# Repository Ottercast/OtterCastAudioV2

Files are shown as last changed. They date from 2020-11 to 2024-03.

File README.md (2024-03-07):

# OtterCastAudioV2

OtterCast is an open-source audio streaming device running Linux.
Based on a Sochip S3 SoC, featuring a Webinterface, shairport-sync, snapcast, Spotify Connect and pulseaudio sink/source.

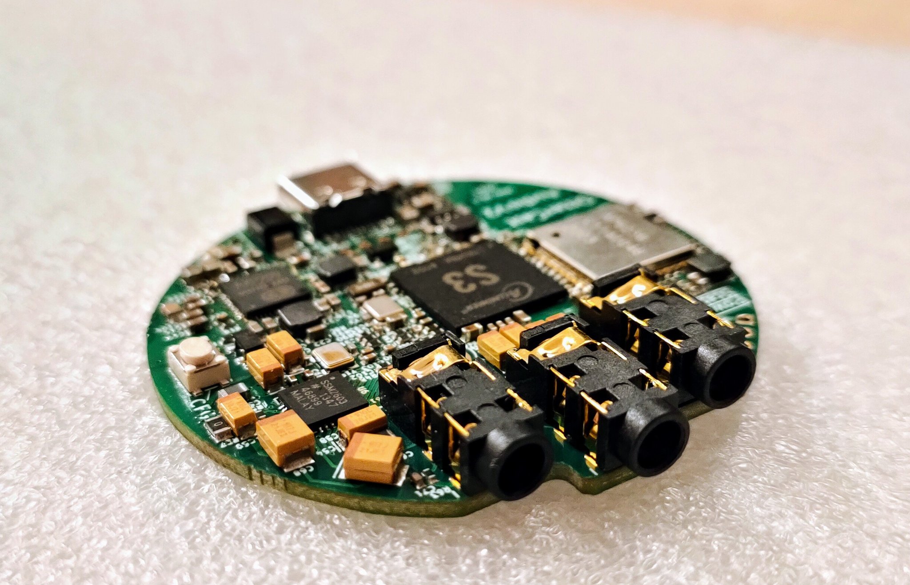
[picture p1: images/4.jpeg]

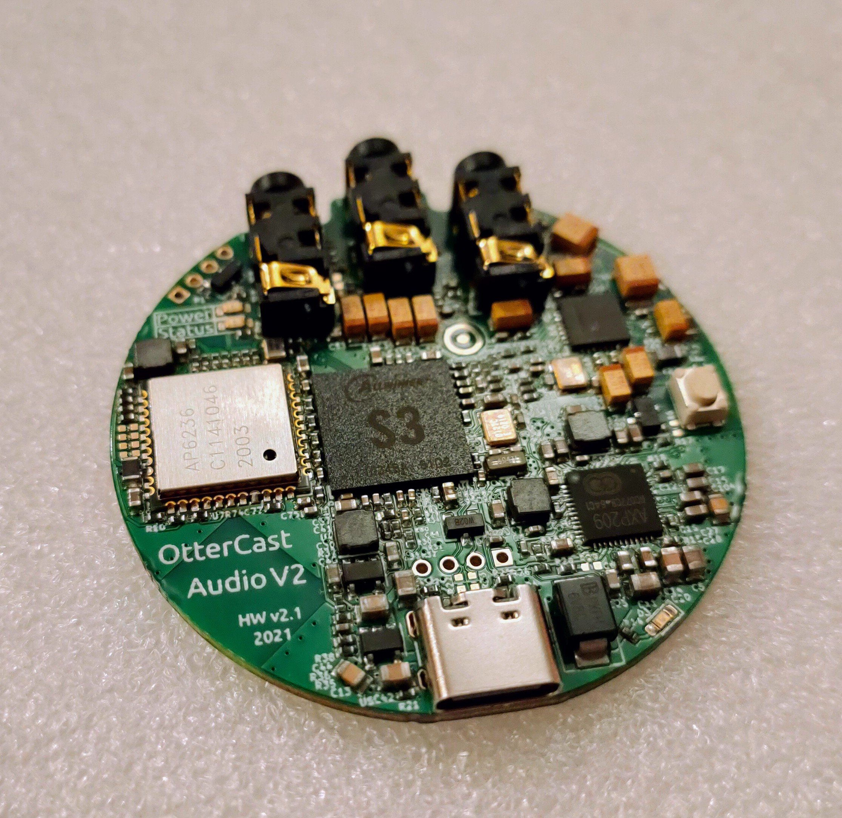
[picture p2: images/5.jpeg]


[Demo Video](https://twitter.com/_Jana_Marie/status/1374088494985969667)

## How do I get one?

~~We are currently planning a small batch production run, stay tuned.~~ Sorry, we don't 🙈

You don't want to wait? You can of course run a small batch on your own! Please have a look into the [production folder](/production_v2.1), a batch size of just 5 (and up to 30) boards is supported by JLC.

## Installation & Configuration

After [downloading and flashing](https://cast.otter.jetzt/docs/firmware/#download-ready-made-images) the image, OtterCastAMP can either be configured via the `config.ini` file or via the web-interface.

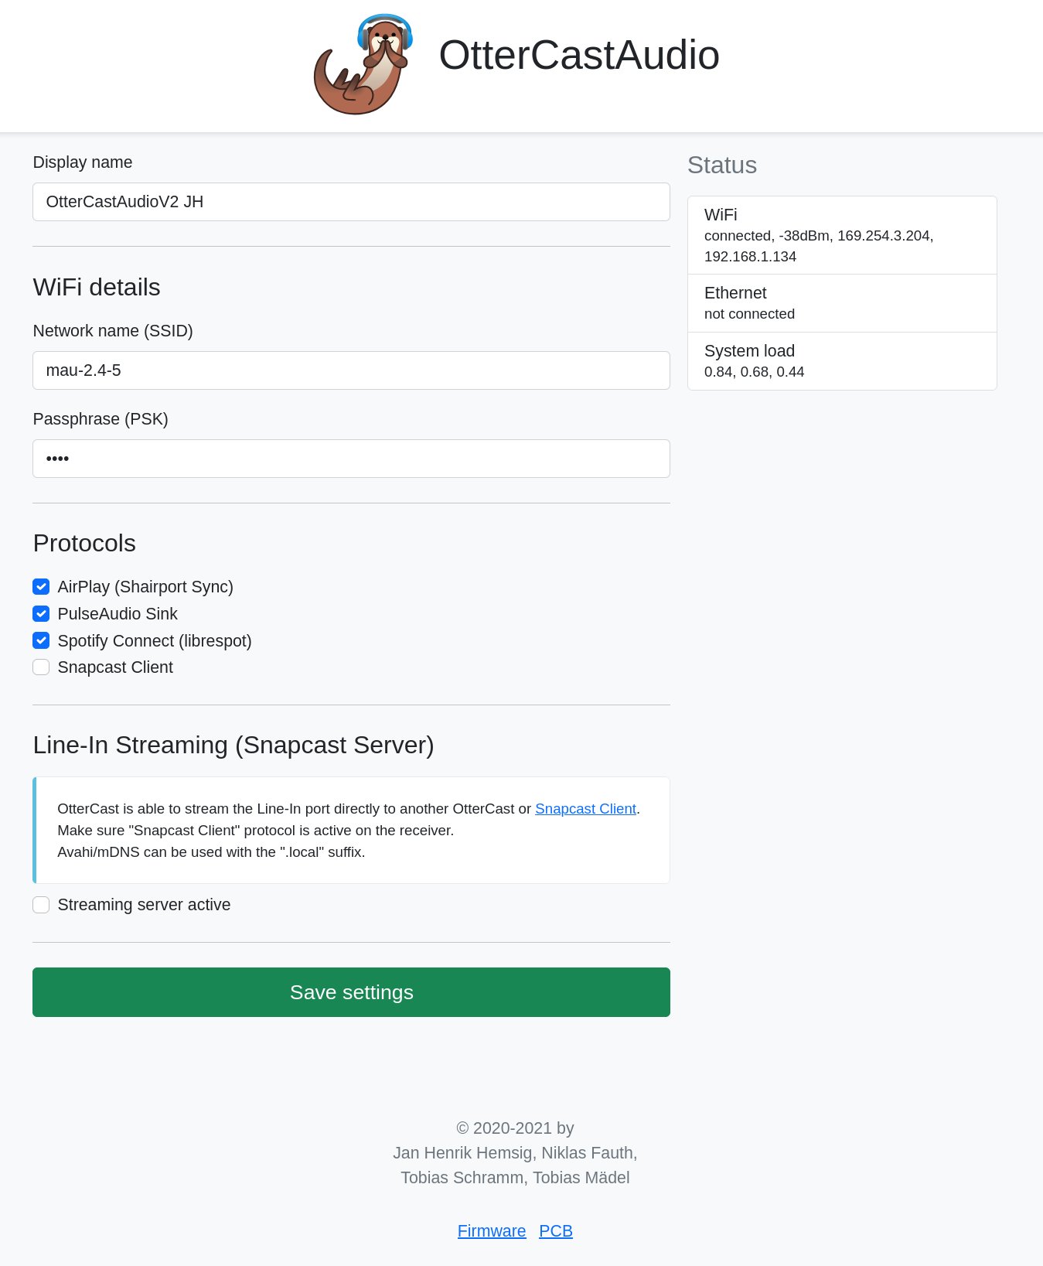
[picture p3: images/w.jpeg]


Check out our [Documentation](https://cast.otter.jetzt/docs/) for more information!

## Schematics?

[Schematics!](/OtterCastAudioV2.pdf)

## Team

 - [@lucysrausch](https://twitter.com/lucysrausch) Hardware - OtterCastAmp
 - [@_Jana_Marie](https://twitter.com/_Jana_Marie) Hardware - OtterCastAudio
 - [@Toble_Miner](https://twitter.com/Toble_Miner) Software - Embedded Linux
 - [@Manawyrm](https://twitter.com/Manawyrm) Software - Frontend & OTA

## What happened to OtterCastAudioV1?

Nobody shall ever know

## Status

HW v2.1 is tested and works!

 - [x] Audio Line Out
 - [x] Audio Headphone Out
 - [x] Audio In
 - [x] WiFi
 - [x] Ethernet
 - [x] USB Sound card mode

 - [x] Webinterface (config)
 - [x] Shairport-sync
 - [x] Pulseaudio sink/source
 - [x] snapcast server/client
 - [x] Spotify Connect (librespot)

## License

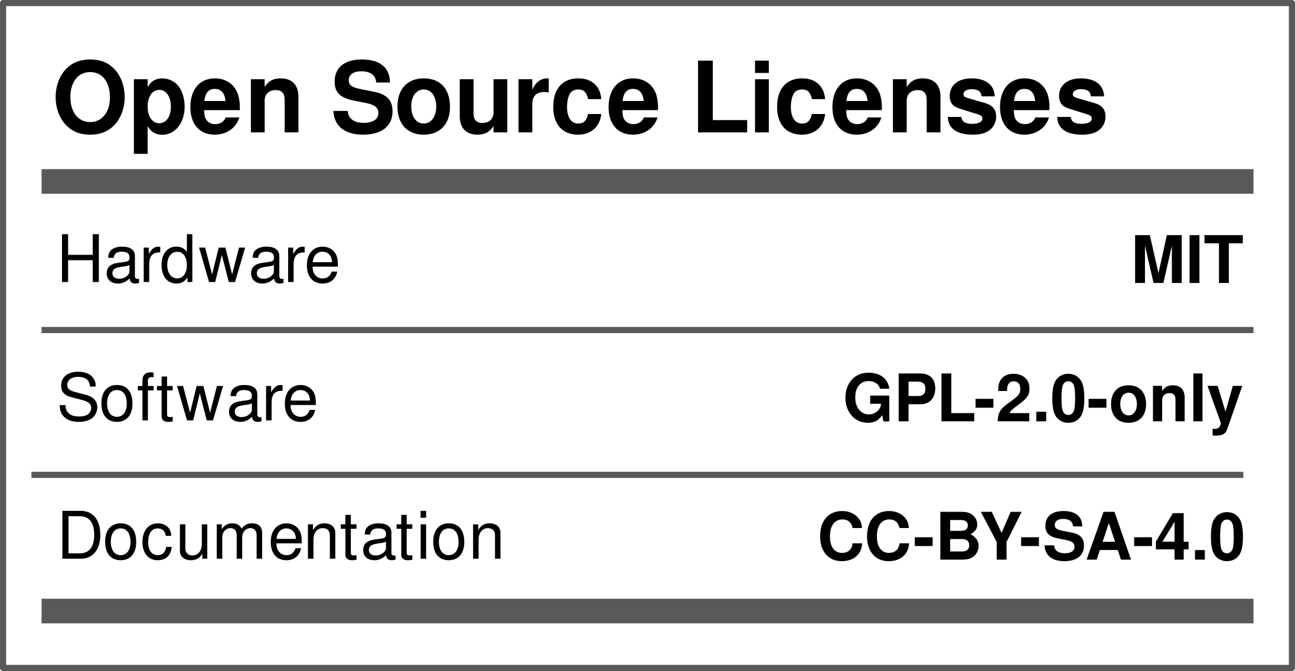
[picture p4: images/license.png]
License Banner (https://certification.oshwa.org/de000109.html)


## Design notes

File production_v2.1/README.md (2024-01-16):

# Notes

All production files are optimized for [JLCPCBs SMT service](https://cart.jlcpcb.com/quote?orderType=1). The gerbers are located in `OtterCast_combined-v2.1.zip` and as for the BOM and position file please refer to `BOM_v2.1.csv` and `POS_v2.1.csv`.

Please choose `1.6mm`, `impedance control`, `ENIG`, `Specify order number location`, `SMT Top side assembly` and `tooling holes added by customer` as board options. 

The `BOM_v2.1.csv` does not contain all parts, since JLC does not sell all parts. Please refer to the following list for the manual assembly parts.

Or [jump to the Images section](https://github.com/Ottercast/OtterCastAudioV2/blob/main/production_v2.1/README.md#jlc-images) of this README to see how to order the boards.

| Designator | Part | Layer | LCSC  | Other |
| --- |:---:|:---:|:-----:|:-----:|
| U1 | Sochip s3 | Top | - | [aliexpress](https://aliexpress.com/item/4000208092272.html) |
| U7 | AP6236 | Top | [C2908817](https://www.lcsc.com/product-detail/WiFi-Modules_AMPAK-Tech-AP6236_C2908817.html) | |
| X1 | 26Mhz TCXO | Top | [C669081](https://lcsc.com/product-detail/SMD-Oscillators-XO_Yangxing-Tech-OT201626MJBA4SL_C669081.html) | |
| U6 | SSM2603 | Top | [C691080](https://lcsc.com/product-detail/Pre-ordered-Products_Analog-Devices_SSM2603CPZ-REEL_Analog-Devices-ADI-LINEAR-SSM2603CPZ-REEL_C691080.html) | [aliexpress](https://www.aliexpress.com/item/33014054478.html) |
| U3 | AXP209 | Top | [C80525](https://lcsc.com/product-detail/PMIC-Battery-Management_X-Powers-Tech-AXP209_C80525.html) | |
| J5,J6,J7 | PJ-3270 | Top | [C381134](https://lcsc.com/product-detail/Audio-Video-Connectors_XKB-Connectivity-PJ-3270_C381134.html) | |
| J2 | DM3D-SF | Bot | [C719027](https://lcsc.com/product-detail/Card-Sockets-Connectors_HRS-Hirose-DM3D-SF_C719027.html) | |
| AE1 | KH-5220-A56 | Bot | [C504003](https://lcsc.com/product-detail/Antennas_Shenzhen-Kinghelm-Elec-KH-5220-A56_C504003.html) | |
| AE1 | 0R 0402 | Bot | [C242160](https://lcsc.com/product-detail/Chip-Resistor-Surface-Mount_PANASONIC-ERJ2GE0R00X_C242160.html) | |

## JLC Images

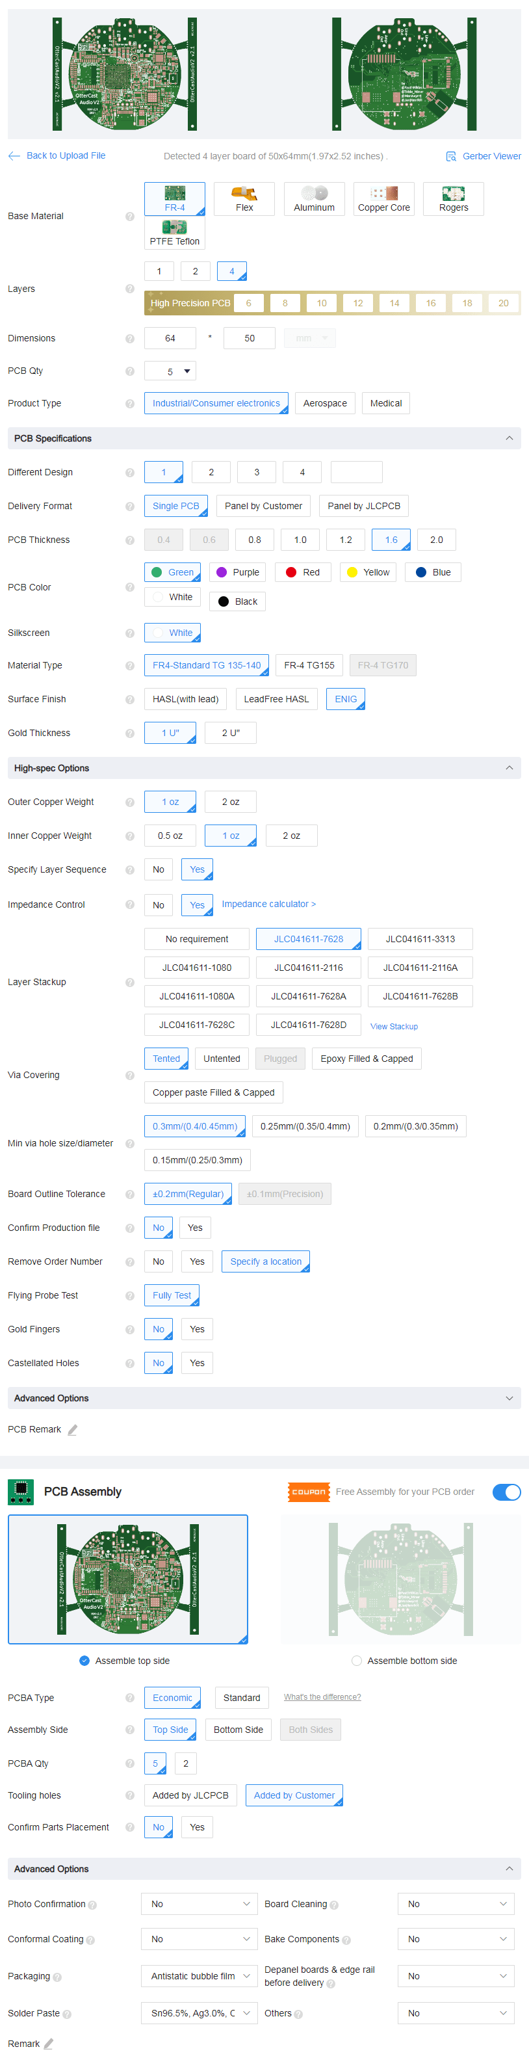
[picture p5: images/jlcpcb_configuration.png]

If you can't select the layer sequence, try changing the *Layers* to 6, then back to 4. For some reason, it sometimes doesn't load correctly on JLCPCB's website.
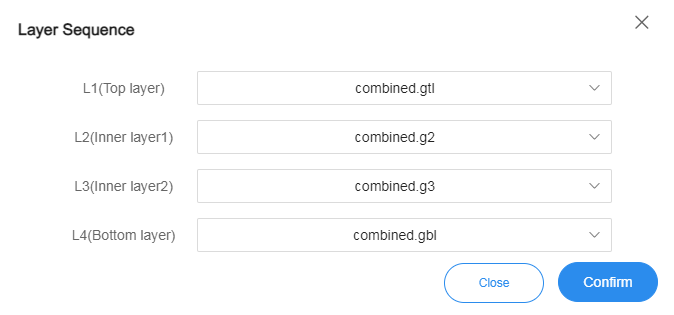
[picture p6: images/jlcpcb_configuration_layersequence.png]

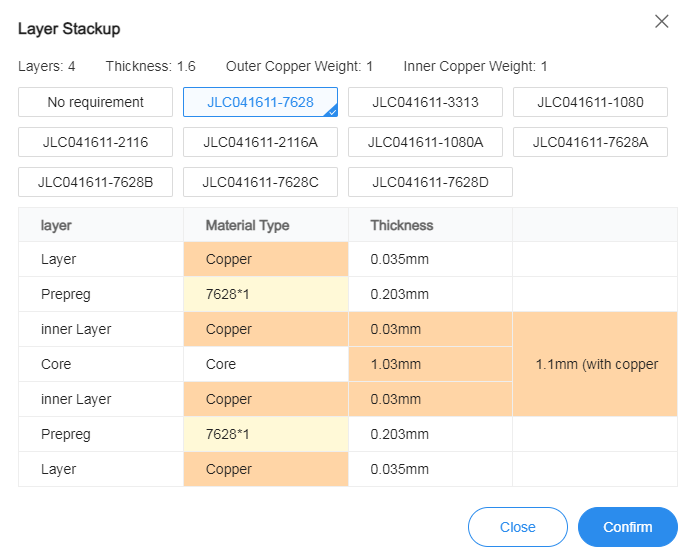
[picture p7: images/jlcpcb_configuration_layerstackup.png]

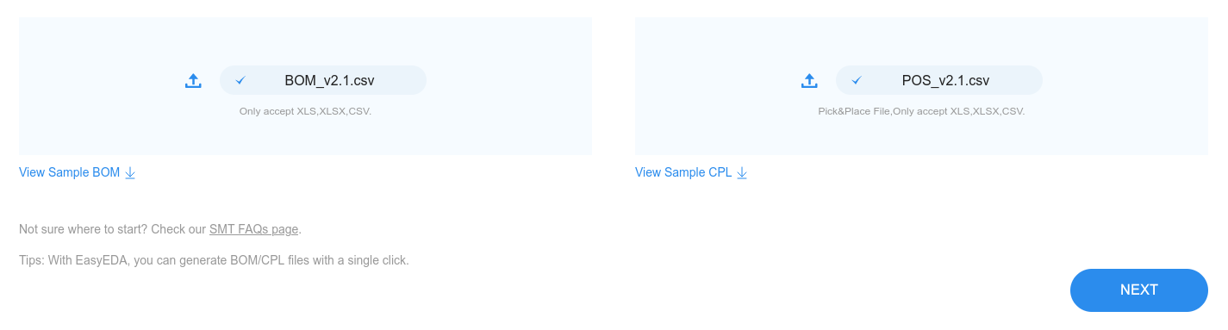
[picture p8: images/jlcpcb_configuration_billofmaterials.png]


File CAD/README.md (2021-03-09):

# OtterCastAudioV2-CAD

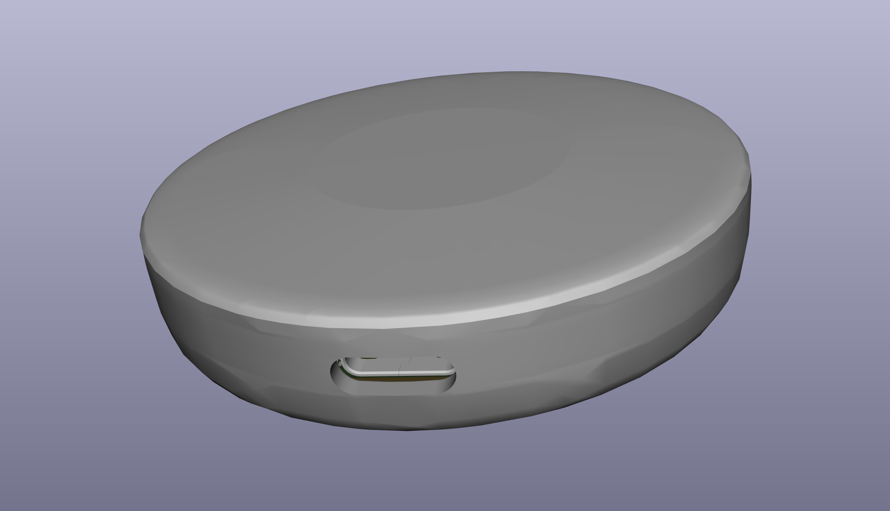
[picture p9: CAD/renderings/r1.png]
Rendering 1 USB

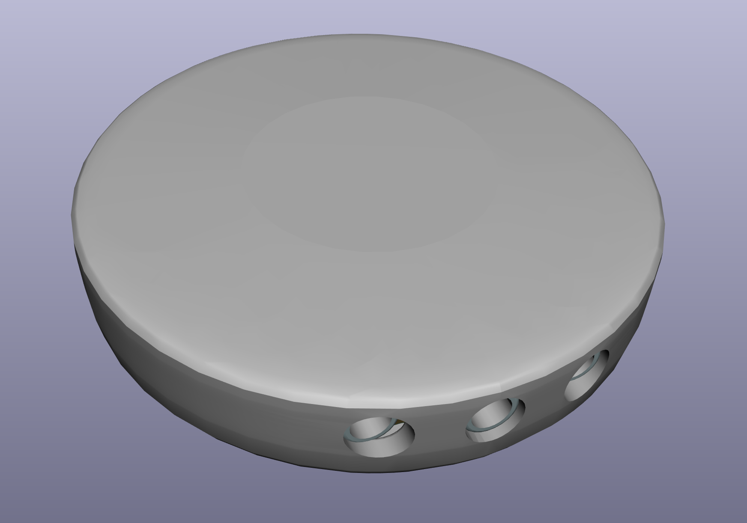
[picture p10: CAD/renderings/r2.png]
Rendering 2 Audio


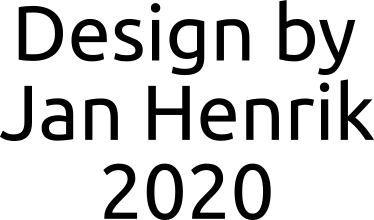
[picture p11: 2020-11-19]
graphics/OtterCastAudioV2_DesignBy.png

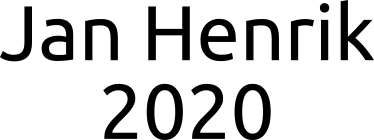
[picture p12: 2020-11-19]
graphics/OtterCastAudioV2_JH_2020.png

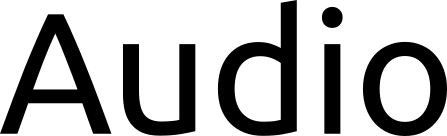
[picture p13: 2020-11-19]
graphics/OtterCastAudioV2_2.png

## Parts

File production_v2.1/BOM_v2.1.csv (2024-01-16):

Comment | Designator | Footprint | LCSC
KH-5220-A56_U.FL | AE1 | otter:KH-5220-A56 | C504003
47u | C11,C10,C5,C42,C43,C45 | otter:C_0805 | C45783
1n | C12,C47 | otter:C_0402 | C1523
1n | C13,C104 | otter:C_0805 | C46653
470n | C2 | otter:C_0402 | C47339
100n | C37,C38,C35,C36,C33,C34,C32,C44,C7,C8,C15,C21,C18,C58,C59,C66,C65,C61,C76,C73,C89,C99,C98,C102,C103,C88,C82,C85,C101,C100,C83,C3 | otter:C_0402 | C1525
10u | C4,C1,C17,C16,C22,C23,C20,C19,C24,C25,C26,C27,C28,C29,C14,C6,C39,C41,C30,C31,C74,C72,C48,C92,C95,C90,C79 | otter:C_0603 | C19702
DNP | C49 | otter:C_0402 | dnp
18p | C52,C51,C93,C94,C96,C97 | otter:C_0402 | C1549
10u | C54,C55,C62,C60,C63,C64,C57,C56,C69 | otter:CP_EIA-3216-10 | C7171
100u | C67,C68 | otter:CP_EIA-3528-12 | C16133
220p | C70,C71,C50,C53,C46 | otter:C_0402 | C1530
1p | C77,C75 | otter:C_0402 | C1550
10p | C78 | otter:C_0402 | C32949
2.2u | C9 | otter:C_0603 | C23630
LED | D1,D2 | otter:LED_0603_1608Metric | C72038
LED | D3 | LED_SMD:LED_0603_1608Metric_Castellated | C72043
P6SMB6.8CA | D4 | Diode_SMD:D_SMB | C78395
ESD5302F | D5,D6 | Package_TO_SOT_SMD:SOT-23 | C239643
FERRET | FB1,FB2,FB3 | otter:R_0805 | C1017
UART | J1 | otter:PinHeader_1x04_P2.00mm_Vertical_nosilk_center | dnp
SD | J2 | Connector_Card:microSD_HC_Hirose_DM3D-SF | C719027
USB | J3 | otter:USB-C 16Pin | C165948
OTG | J4 | otter:PinHeader_1x04_P2.00mm_Vertical_nosilk_center | dnp
PJ-3270 | J7,J6,J5 | otter:PJ-3270 | C381134
49F-1201GYD2NL | J8 | otter:49F-1201GYDXNL | dnp
2.2uH | L2,L1,L3,L4 | Inductor_SMD:L_Taiyo-Yuden_MD-3030 | C167747
2.2uH | L5 | otter:L_0402 | C84472
Mic | MK1 | otter:B4013AM422-42 | dnp
DTA114YKA | Q1 | Package_TO_SOT_SMD:SOT-23 | C111713
100 | R1,R33,R32,R61,R62 | otter:R_0402 | C25076
200k | R16,R21,R40,R78 | otter:R_0402 | C25764
22 | R2,R34,R15,R54,R77,R76,R81 | otter:R_0402 | C25092
0R | R27 | otter:R_0805 | C17477
2k2 | R28,R37,R17,R50,R51,R49,R48,R41,R87,R88,R79,R80 | otter:R_0402 | C25879
DNP | R29,R22,R23,R6,R47,R52,R69,R68,R67,R66 | otter:R_0402 | dnp
5k1 | R3,R4,R30,R35,R36,R39,R24,R25,R14,R86 | otter:R_0402 | C25905
3k3 | R31 | otter:R_0402 | C25890
3k9 | R38 | otter:R_0402 | C51721
680 | R43 | otter:R_0402 | C25130
0 | R44,R45,R46 | otter:R_0402 | C17168
47k | R7,R8,R9,R10,R11,R12,R13,R26,R18,R58,R60,R59,R63,R42,R73,R72,R71,R70,R65,R64,R75,R74 | otter:R_0402 | C25792
240 | R82,R83 | otter:R_0402 | C25094
10M | R84 | otter:R_0402 | C26082
6k04 | R89 | otter:R_0402 | C25913
51 | R91,R90,R93,R92 | otter:R_0402 | C25125
RST | SW3 | otter:SW_SPST_PTS810 | C92589
AllWinner-S3(FBGA-234) | U1 | otter:FBGA-234(Pitch-0.65mm_Pad-0.3mm_11x11x1.08mm) | C2886811
AXP209(QFN-48) | U3 | otter:QFN-48-1EP_6x6mm_P0.4mm_EP4.05x4.05mm | C2997895
SY8089AAAC | U4 | Package_TO_SOT_SMD:SOT-23-5 | C78988
SY6280AAC | U5 | Package_TO_SOT_SMD:SOT-23-5 | C55136
SSM2603 | U6 | otter:LFCSP-28-5x5mm-0.5mm-EP3.14x3.14mm | C691080
AP6236 | U7 | otter:LGA_44_12x12mm_0.9mm | C2908817
26Mhz TCXO | X1 | otter:2016_SMD_CRYSTAL | C132147
12.288Mhz | Y1 | otter:Oscillator_3225 | C70567
32.768kHz | Y2 | otter:Crystal_SMD_3215-2Pin_3.2x1.5mm | C32346
24MHz | Y3 | otter:Oscillator_3225 | C89577

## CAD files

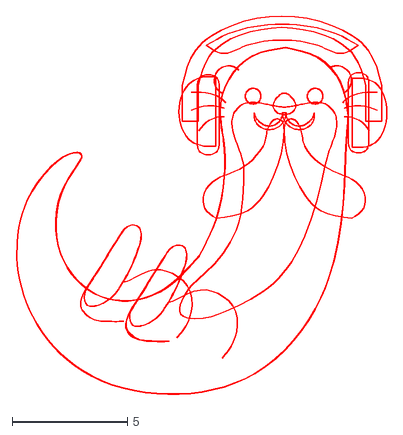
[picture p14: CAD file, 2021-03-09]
CAD/OtterCastLogo.dxf
16.1 x 16.5

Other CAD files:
CAD/case_bot.ipt
CAD/case_top.ipt

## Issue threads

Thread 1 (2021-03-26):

JLC reported issue with trace near PCB edge

Manawyrm, 2021-03-26:
Kenny Stier reported:
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

This'll probably be fixed by resubmitting (maybe without impedance control), but updated gerbers (if possible) would be ideal.

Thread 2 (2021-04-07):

Does it support the Chromecast API?

FutureSharks, 2021-04-07:
Like can I just "cast" from all apps on my android phone?

Jan--Henrik, 2021-04-07:
Sadly the "cast" protocol used by google is not open source nor is there any compatible open source software. It is not supported, so no.

FutureSharks, 2021-04-07:
That's a shame but there is some other reverse engineered examples I think?

https://github.com/ajhsu/chromecast-device-emulator
https://github.com/vbaicu/mMusicCast

Gartral, 2021-04-07:
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

I'm just doing my toes into the otter cast project, so this is a high level skim of the above projects. At first glance it appears that mMusicCast is closer to what you're looking for, but I have serious missgivings about trying to shoehorn a full electron app into 128mb of RAM.

I'll profile MMC later today and update from there. If it fits, this might be as simple as bake it in and turn it on.

CDE isn't suitable at all from their own admission of having to previously have a cast "sink" and basically doing a replay attack to force an app to talk to the server. Seems like it's more geared for having together your own castable apps rather than using it as a legit sink.

Jan--Henrik, 2021-04-07:
Thanks @Gartral! As a sidenote, MMC does not seem to be a "cast" receiver, it is just a spotify and youtube receiver. We already support spotify, so this does not add alot.

Gartral, 2021-04-07:
Yea, MMC is only a partial implementation of the Cast/mDNS protocol. From what I can tell so far, Google Cast is a "closed ecosystem, with an open door". I popped the $5 to poke around in the google Cast Dev SDK site and I see an option for making a new receiver. Now, if my understanding of mDNS and the Cast Protocol works, we aren't exactly piping audio straight from one device to another, as we are requesting the cast receiver to go find what we asked it to play and just play it, on it's own.

In short, while it DOES look like we can implement Cast Audio on the ottercast, this will incur a running cost as we're going to need a publicly accessible server to "bounce" off of, and is partially reinventing the wheel for the project as Cast appears to be a loose collection of apps that all agree that Cast is an acceptable user agent, more than it is just a direct pipe. It's possible to implement, but the question is; Is it worth it? And worth how much?

Manawyrm, 2021-04-08:
`publicly accessible server`
-- running servers is no issue, we have more than enough infrastructure at hand.

I'd like if that infrastructure could be self-hosted, though, to avoid shutting down people's OtterCast when our servers go down.

I'm personally using no devices capable of sending the Cast protocol, but would still be interested in implementing the feature.
Can you assess whether that server would actually need to transport any media data or just handshaking/API calls?
I'm guessing this would require some serious development time, though :/

Gartral, 2021-04-13:
Sorry! my laptop was down for a few days (keyboard died). As far as I understand it, the Cast protocol doesn't stream the data itself from device to device, but the server is needed as a common reference point to do NAT walking and handshakes. The dev work, after digging into it, doesn't look like it's insurmountable but it WILL require shoehorning a "minified" Google Chrome browser into the OtterCast.

And I know from experience that the google home mini speakers can be used with some specific software on Linux as a target for pulse, but the latency is absolutely atrocious, on the order of seconds. The best I've been able to get is 3-4 seconds behind a youtube video. The average, without mucking around with a lot of networking first, is closer to 10 often north of that. And while I haven't looked directly, I suspect part of that is the handshake, I'll dig more into it.

In short: I don't personally see it as a good alternative to the other capabilities that the Ottercast has built in. It would only really be usable to cast audio from a phone to the OC.

Manawyrm, 2021-04-13:
> require shoehorning a "minified" Google Chrome
Yeah, I don't see this happening at all on the platform.
With 128 MB RAM (half of it is already used) and the rather slow 32bit ARMv7, running any kind of CEF, WebKit, Chromium, etc. is pretty much out of the question.

Gartral, 2021-04-13:
64MB of ram is... doable. It'd be tight as hell, don't get me wrong, but it may well be doable. The original Nest Mini had a Synaptics AS370 with 256MB of ram.

Of course, the latest gen is the Home Mini with a Marvell 88DE3006 and 512MB of RAM. But if we're too clever by half, and disable a bunch of features when we're in "Cast mode" then we might be able too eek out a usable experience. This again wraps back around to my original point of "How badly do we want this?". if we're careful and manage it right, it might be doable.

I'm looking into how much of the Nest/Home's ram is used by the "os" and there isn't a lot of info there. But I suspect the actual usage for Cast/mDNS isn't too far off our target (Keeping in mind that the google devices have so far, to my knowledge, never been hacked and firmware dumped)

blurpy, 2021-06-26:
> How badly do we want this?

I've been looking for an alternative to the Chromecast Audio for years, so I dread the day my old one dies. Google only wants to sell speakers, and the other options are usually quite expensive and big.

I don't know if it will work on the current generation of hardware or not, but making a device that accepts casts from any audio app on Android is really useful. And even better if it supports toslink, for a full Chromecast Audio replacement.

raress96, 2022-06-22:
Just came across this issue while searching for an Open Source Google Cast receiver.
I presume this is not going to be implemented any time soon right?

phaidros7, 2025-04-15:
Actually 2 questions:

1)

Maybe I am on the wrong foot here and even be reanimating a corpse of a feature request .. but for the sake of having a dozen Chromecast Audio Devices in my home and in the desperate search for suitable wifi enabled sink devices (turntable!), I came across Otter :)

All Otter Chromecast Audio compatibility related docs lead to this ticket.

I understand that Chrome on the device is to bloated, but I am using mkchromecast rather successfully from my linux clients and wonder, if that is something the Otter is maybe capable to run:

https://github.com/muammar/mkchromecast

If so, would it be useful to incorporate?

2)

My second question is: was there any approach to Google if they might open up the Cast protocol already? What would be a way to address that with them?

I'd love  to see and support a solution with which the old Chromecast Audio Devices are given a way longer live.

Manawyrm, 2025-04-15:
> I understand that Chrome on the device is to bloated, but I am using mkchromecast rather successfully from my linux clients and wonder, if that is something the Otter is maybe capable to run:

Isn't this the wrong direction? This looks like it's a tool to stream audio _TO_ other Chromecast devices.

phaidros7, 2025-04-15:
> > I understand that Chrome on the device is to bloated, but I am using mkchromecast rather successfully from my linux clients and wonder, if that is something the Otter is maybe capable to run:
>
> Isn't this the wrong direction? This looks like it's a tool to stream audio _TO_ other Chromecast devices.

Nope, it is actually what I am looking for: an open source software/hardware bundle to use as a source for my network audio, and for now the sinks are Chromecast Audio.

I understood otter to be able to get a line signal and distribute it to the other otter devices in the network, is that correct?

Manawyrm, 2025-04-15:
> Nope, it is actually what I am looking for: an open source software/hardware bundle to use as a source for my network audio, and for now the sinks are Chromecast Audio.

Ah! OK -- that's not what most people here are looking for :)
It could probably be implemented, but you're the first person asking for that 😸

I think I'd recommend getting a regular Raspberry Pi with an external sound card and just running mkchromecast on that...

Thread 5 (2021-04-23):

TOSLINK suport

jonfen, 2021-04-23:
Any plans to support TOSLINK like Chromecast Audio did?

https://www.carousell.sg/p/chromecast-audio-3-5mm-mini-toslink-to-toslink-optical-cable-119491765/

Manawyrm, 2021-04-23:
The current hardware connects the I2S audio directly into the DAC / audio-codec, but there's a device in planning, which should be able to do either SPDIF/Toslink. No more detailed infos, yet, sorry!

dearchap, 2022-02-28:
Looks like the BT module is connected to the Allwinner via the I2S pins.

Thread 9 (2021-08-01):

What DAC is onboard?

Jakobovski, 2021-08-01:
Very cool project!

I am wonder what DAC you have chosen for the device?

Manawyrm, 2021-08-01:
Hi!

It‘s an Analog Devices SSM2603!
Technically it‘s a DSD/1-bit DAC.

Jakobovski, 2021-08-01:
Cool!

Closed 2021-08-01.

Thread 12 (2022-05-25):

Integrated circuit shortage or obsolete parts management

Marin-Dodouss, 2022-05-25:
Hello Ottercast hardware and firmware developpers,

I downloaded Ottercast open source project.
First, a huge thanks because it was exactly what I was looking for.
Then, I tried to order the assembled PCB but some components are noted as inventory shortage on JLCPCB. (On octopart too)
Maybe, I can found alternate parts for some, but the AXP209 seems unavailable.

Did you plan to change this component ?

If you need, I think I can made a fork and do components changes using Kicad but I don't know if doing this will broke the software or not.

Do you have any advices ?

Manawyrm, 2022-05-25:
Hi!
IIRC the AXP currently isn't really used in the software, so anything that can supply the required voltages (with the required power sequencing) should do the trick.
There are a lot of similar chips in the AXP line, you might find a compatible one.

Marin-Dodouss, 2022-05-25:
Hi !
Thanks for your quick answer !
I'll try to find an alternate part next week.
If it's okay, I'll put it into the BOM.

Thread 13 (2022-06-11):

AirPlay 2 Compatibility?

ezadoo, 2022-06-11:
As Shairport-Sync seems to be in the final stages of implementing the AirPlay 2 functionalities, it would be very interesting to know if there is
a) a way of installing the beta-version of shairport-sync
and b) how it will perform on OttercastAudioV2, if it is released.

As I currently don’t have an Device myself, as I hoped I would be able to simply buy a completely working OttercastAudio-board.
And if If i do the additional soldering myself, I would like to know, if I could use it later for AirPlay 2 too.

Manawyrm, 2022-06-11:
> AirPlay 2 functionalities
Yeah, AirPlay 2 is much more involved than AirPlay 1, as it needs strict timing accuracy, would normally also require additional hardware features (but I think we can manage without them).

Generally: The firmware for the Ottercast is built via buildroot from this repository:
https://github.com/Ottercast/buildroot-ottercast-audio
We're already using a custom version of shairport-sync with some mods, which is currently hosted on my GitHub account:
https://github.com/Ottercast/buildroot-ottercast-audio/blob/master/buildroot/package/shairport_sync_pulseaudio/shairport_sync_pulseaudio.mk
This would need to be changed to use the development branch (or the new version when it's released).

Getting the dev version / v2 to work with PulseAudio in general might be a bit of a pain. Maybe it's time to evaluate Pipewire first (or to switch to plain ALSA outright)... The OttercastAmp (not the AudioV2) also seems to still be suffering from some timing / clock-distribution problem which would probably need to be addressed before this starts working properly.

Performance-wise: I don't really expect any trouble there.

... to be direct: Each single one of us in the team have started a new full-time role as an engineer at different companies since we started this project, so time is running a bit low. The OttercastAmp is my daily driver amp and it has reached that status of "good enough, plays music, can worry about other things", which is a dangerous place to be in :smile:

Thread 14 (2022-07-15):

NymphCast support

keunes, 2022-07-15:
Hello
I've been watching this space for a while and it's really cool what you folks are making :) I'm currently using Chromecast a lot but interested in replacing it with an open source stack (so I've following #2 also).

Now, I've also seen NymphCast, some kind of an open source Chromecast replacement, which looks cool as well. Not sure if you were aware of it, so I thought I'd share.

https://github.com/MayaPosch/NymphCast

Quite far away still, but the ultimate dream is to stream audio from AntennaPod and Funkwhale, via NymphCast, to OtterCast :)

keunes, 2022-07-15:
Just realised that there's another repo for the software side, which even already has an issue for NymphCast! 💪
https://github.com/Ottercast/buildroot-ottercast-audio/issues/16

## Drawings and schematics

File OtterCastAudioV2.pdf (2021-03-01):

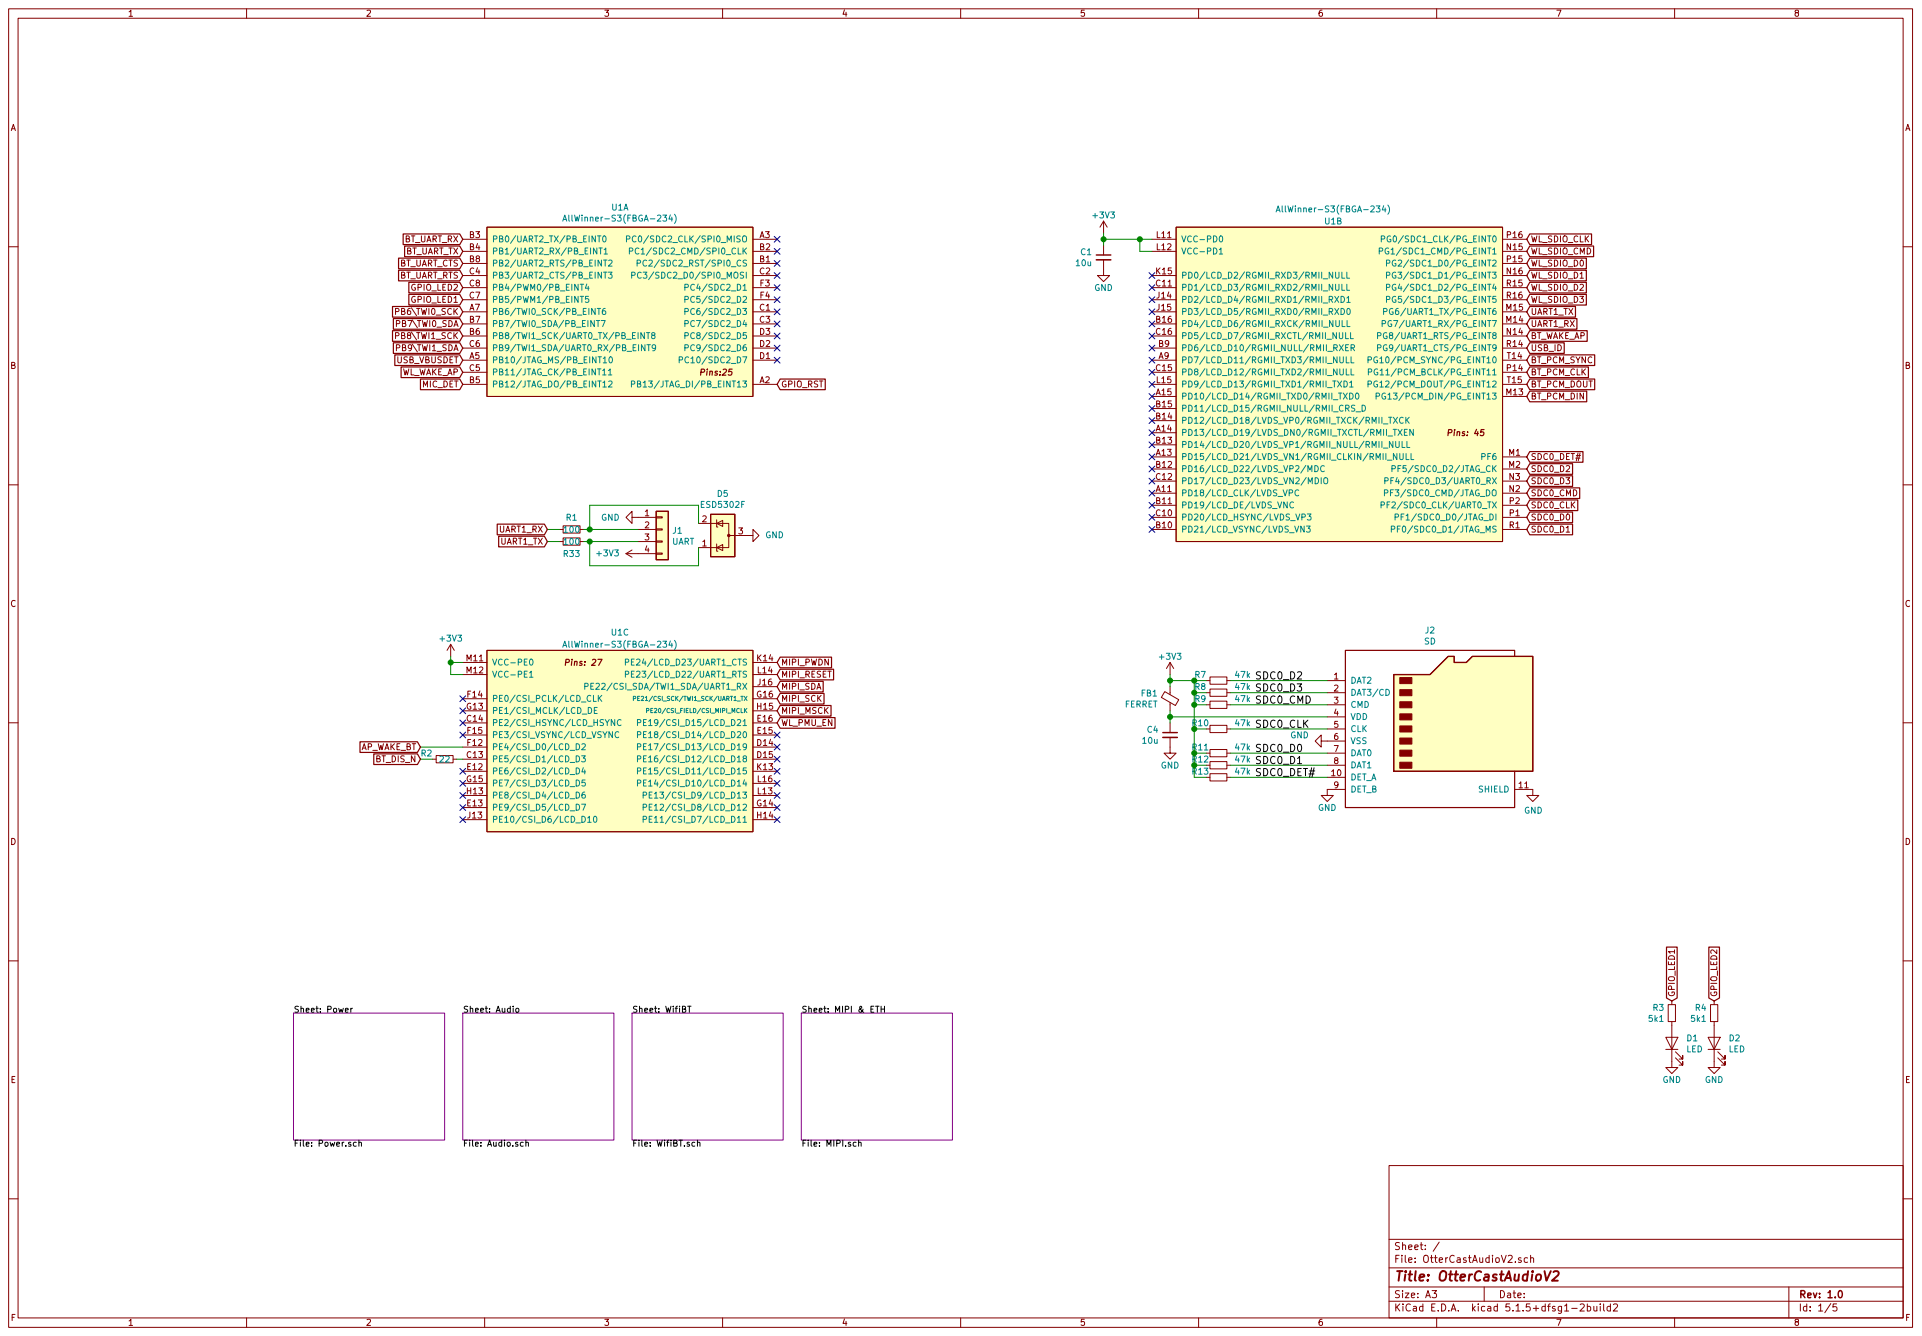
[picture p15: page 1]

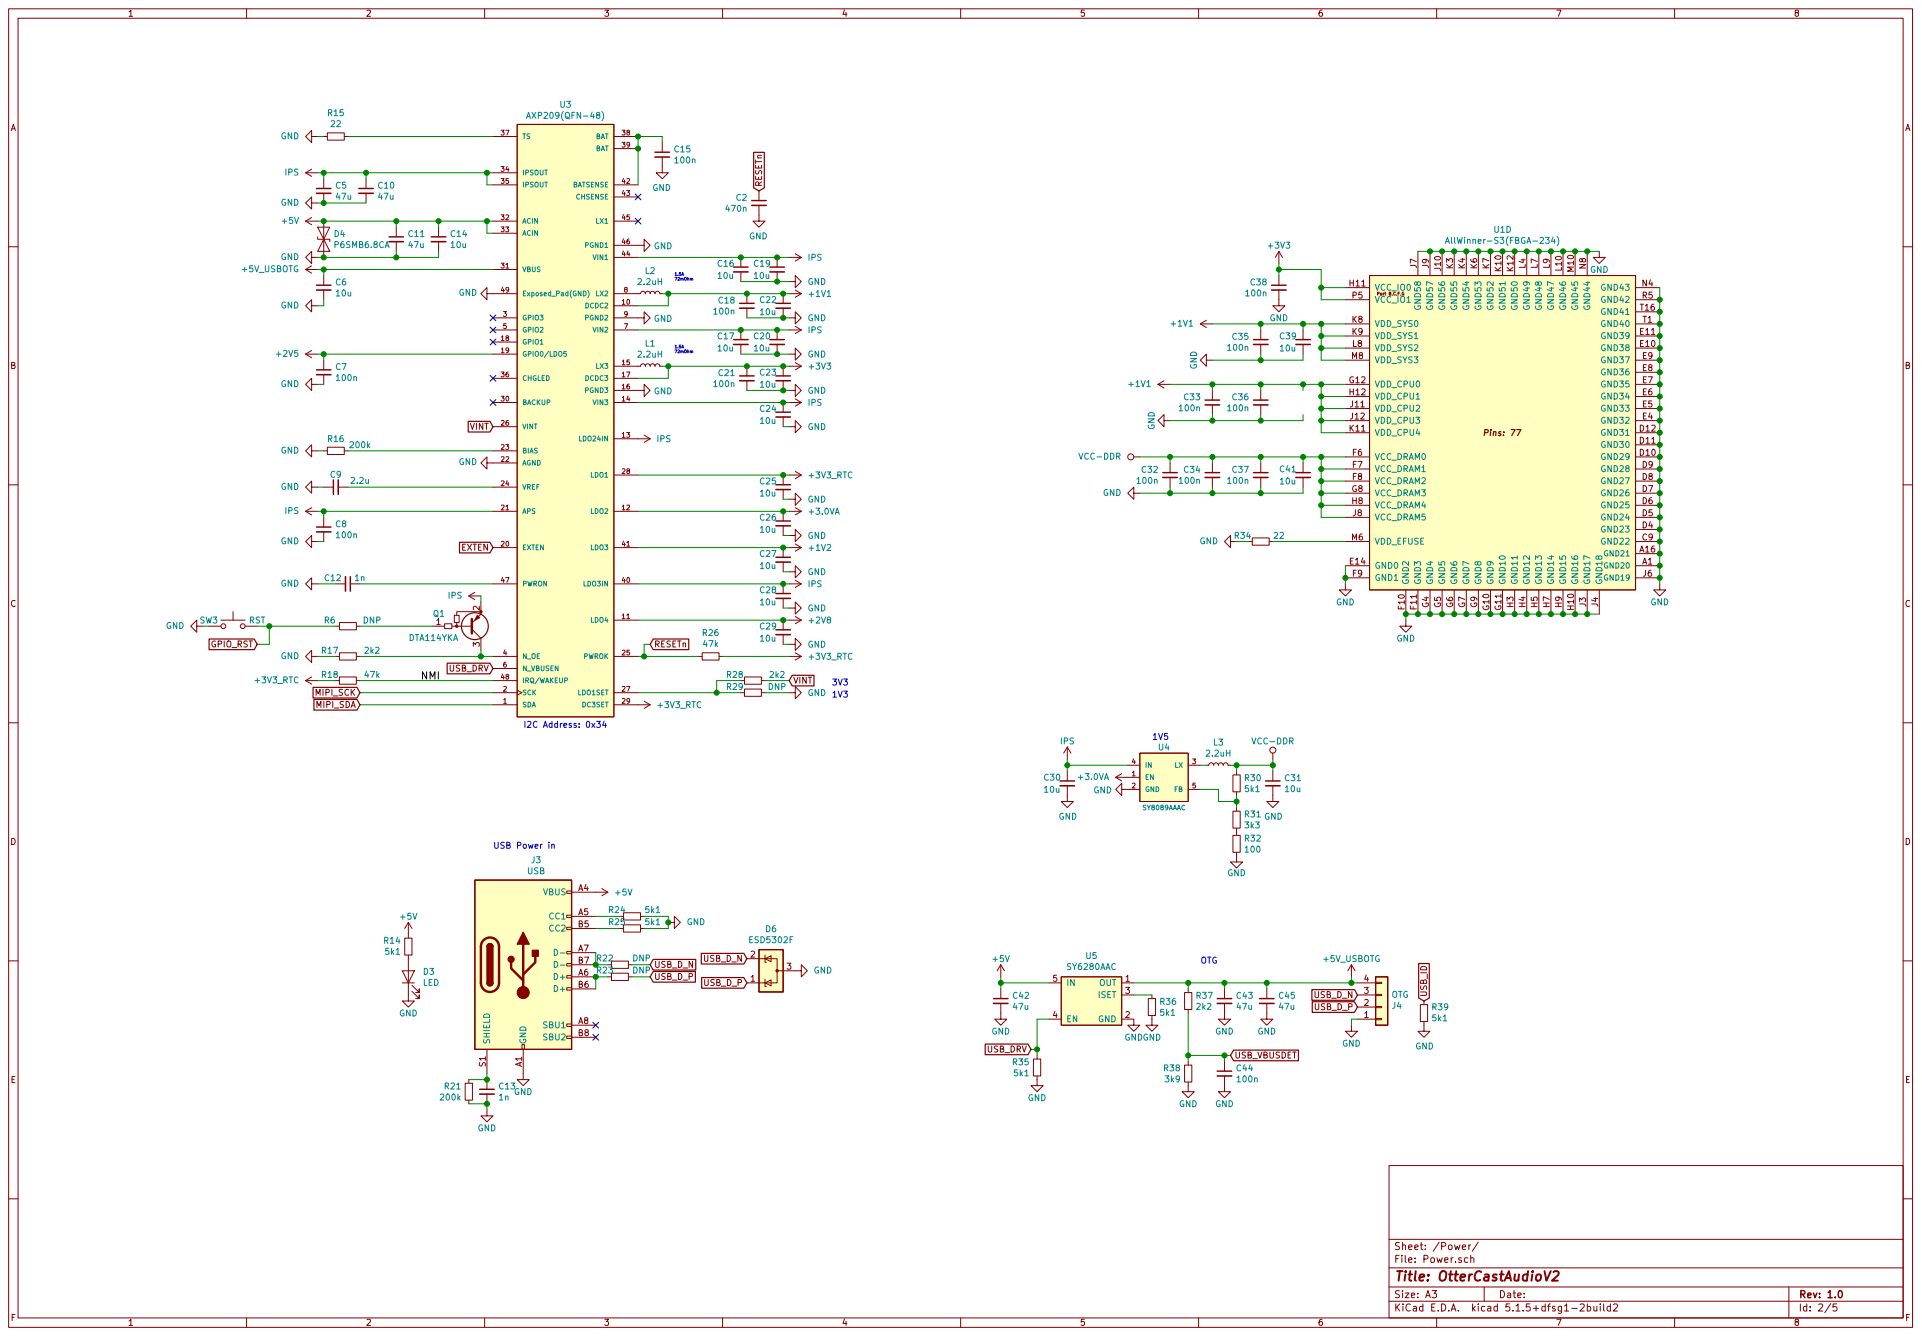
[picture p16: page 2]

File: Power.sch Sheet: /Power/
Id: 2/5 Title: OtterCastAudioV2

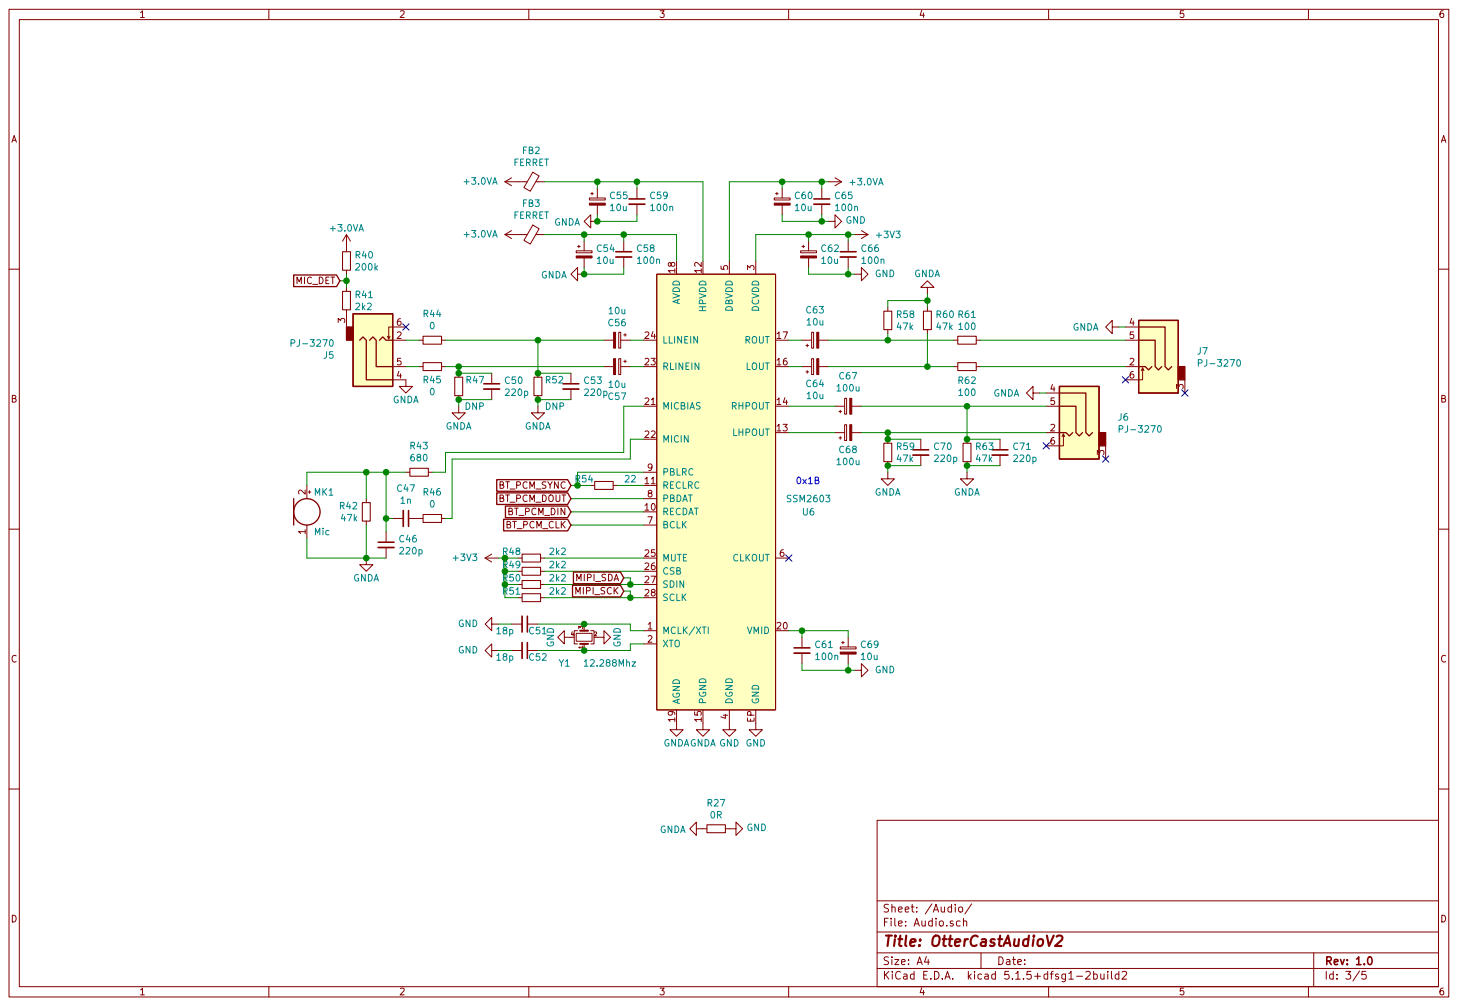
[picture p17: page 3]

5 CLKOUT 6 BCLK 7 PBDAT 8 PBLRC 9 GND EP U6 SSM2603

File: Audio.sch Sheet: /Audio/
Id: 3/5 Title: OtterCastAudioV2

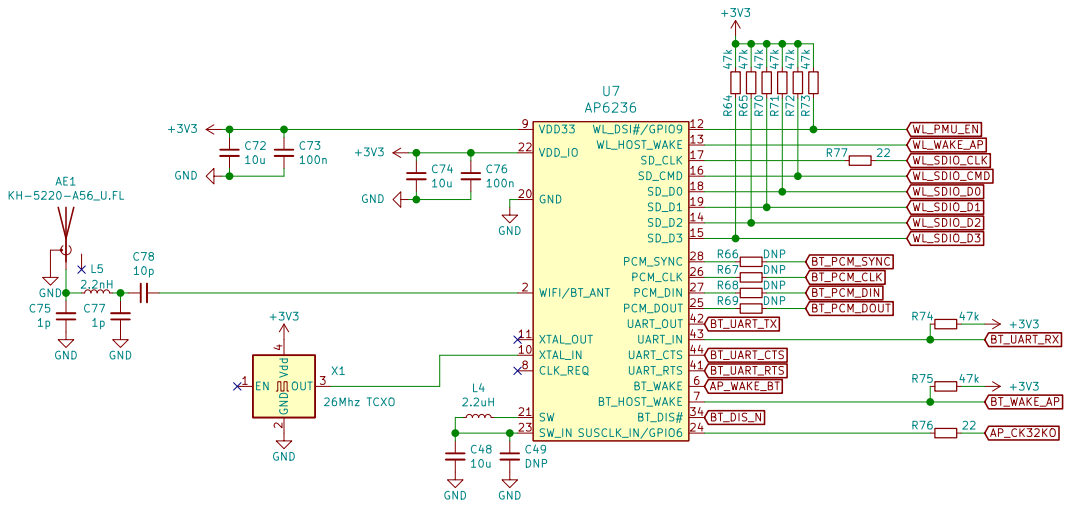
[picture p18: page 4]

File: WifiBT.sch Sheet: /WifiBT/ C75

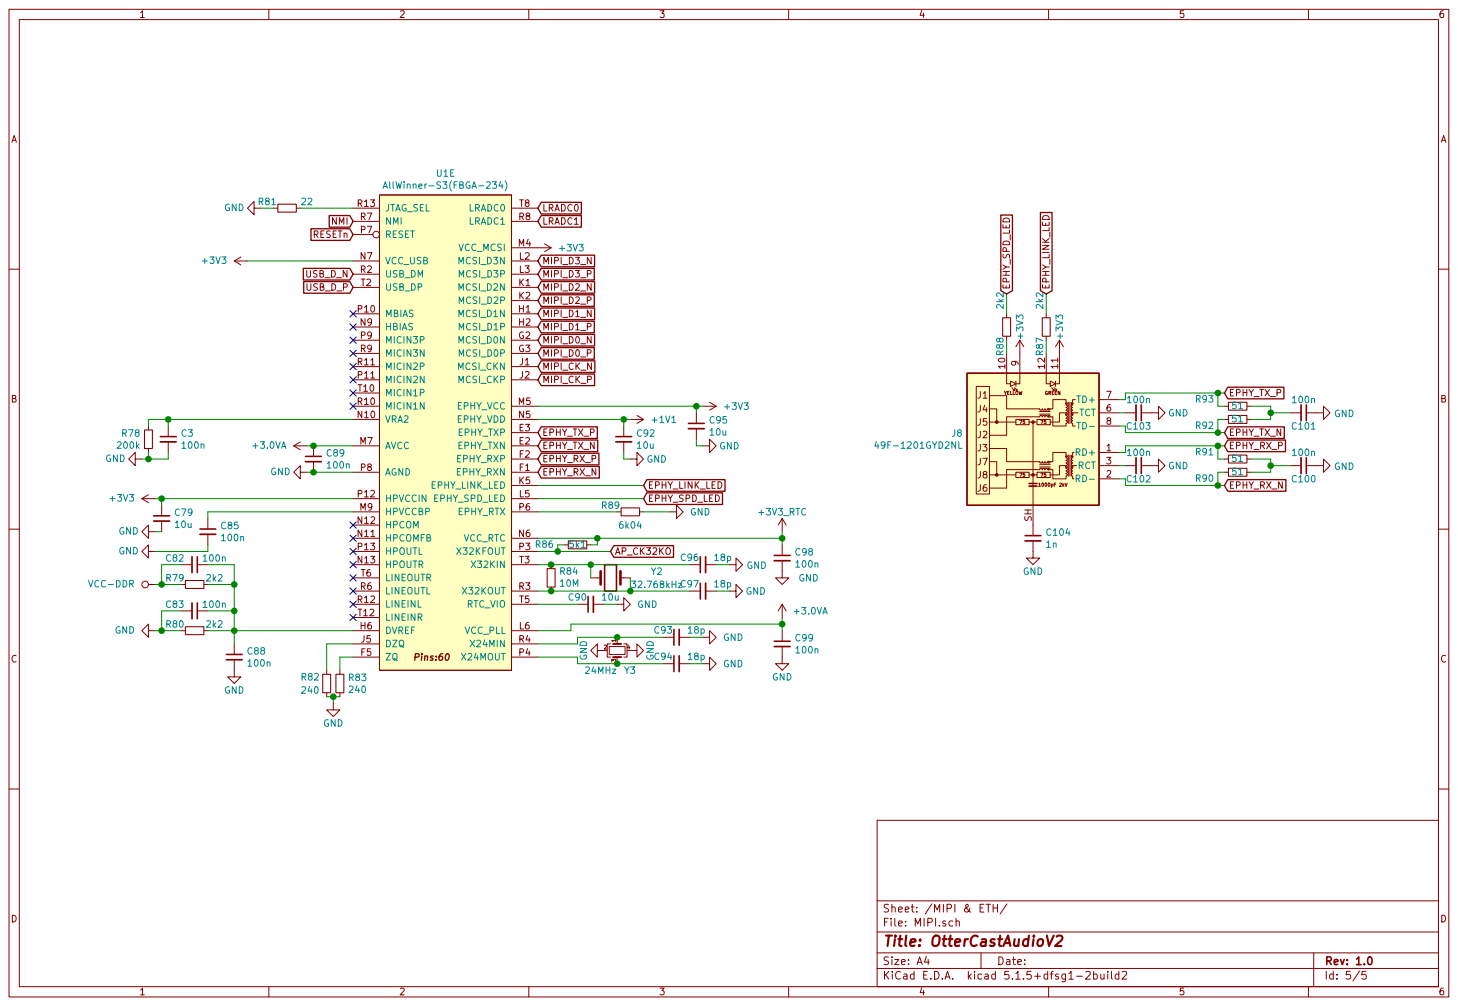
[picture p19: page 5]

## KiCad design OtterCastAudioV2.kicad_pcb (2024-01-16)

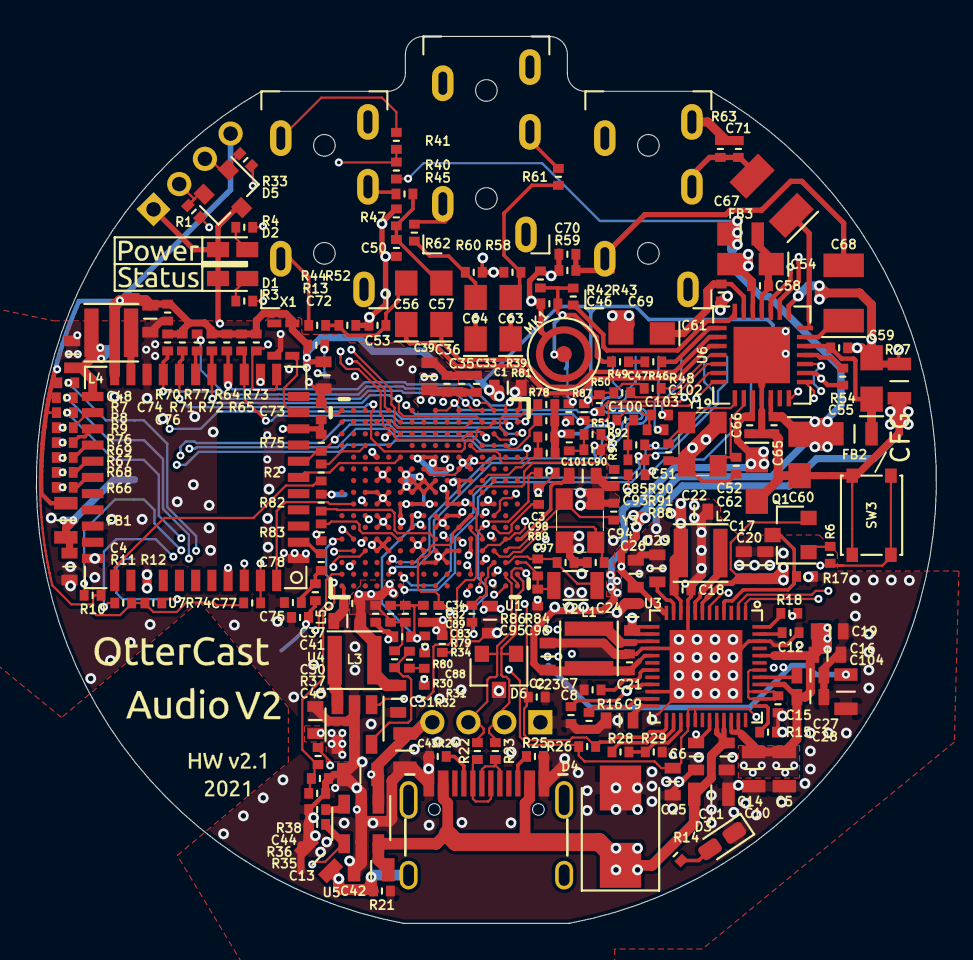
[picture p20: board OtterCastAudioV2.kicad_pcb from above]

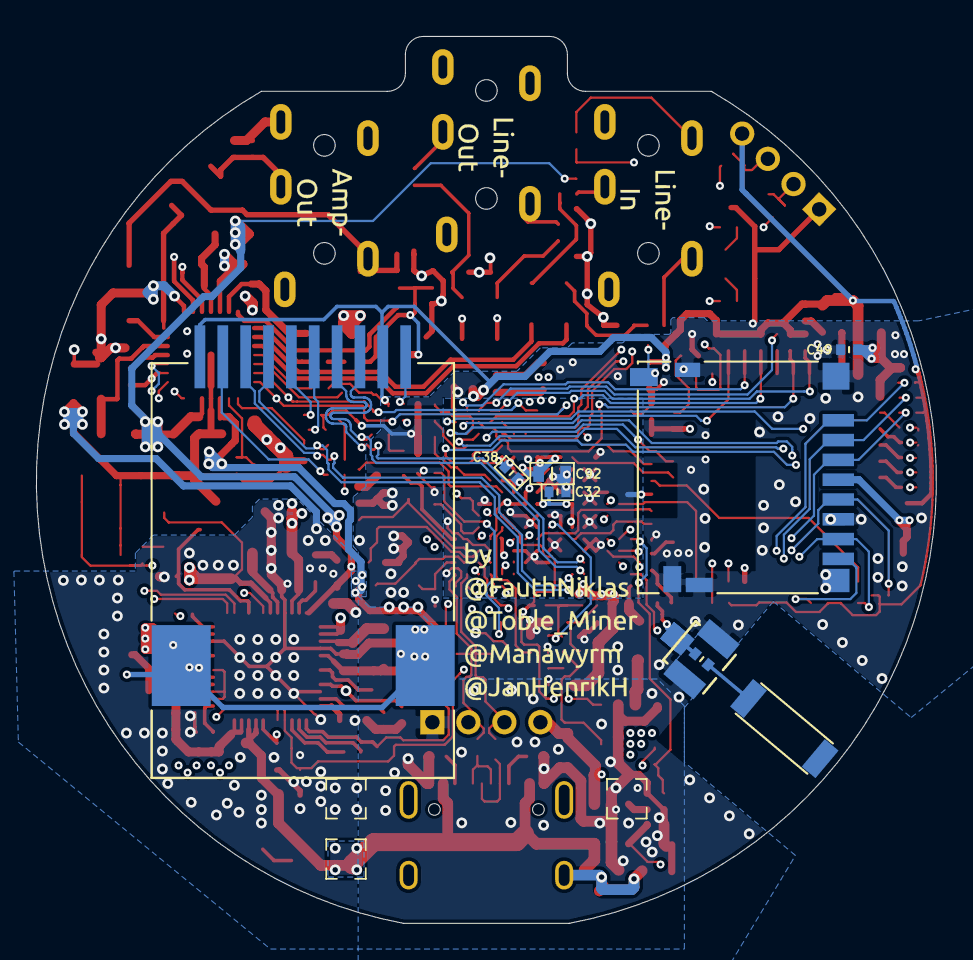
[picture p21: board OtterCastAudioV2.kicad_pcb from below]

Board: 4 copper layers, 50.0 x 49.3 mm, 216 parts (7 on the bottom side), 149 nets.

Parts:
AE1: KH-5220-A56_U.FL; KH-5220-A56
C1, C4, C6, C14, C16, C17, C19, C20, C22, C23, C24, C25, C26, C27, C28, C29, C30, C31, C39, C41, C48, C72, C74, C90, C92, C95: 10u; C_0603
C2: 470n; C_0402
C3, C7, C8, C15, C18, C21, C32, C33, C34, C35, C36, C37, C38, C44, C58, C59, C61, C65, C66, C73, C76, C82, C83, C85, C88, C89, C98, C100, C101, C102, C103: 100n; C_0402
C5, C10, C11, C42, C43, C45: 47u; C_0805
C9: 2.2u; C_0603
C12, C47: 1n; C_0402
C13, C104: 1n; C_0805
C46, C50, C53, C70, C71: 220p; C_0402
C49: DNP; C_0402
C51, C52, C93, C94, C96, C97: 18p; C_0402
C54, C55, C56, C57, C60, C62, C63, C64, C69: 10u; CP_EIA-3216-10
C67, C68: 100u; CP_EIA-3528-12
C75, C77: 1p; C_0402
C78: 10p; C_0402
D1, D2: LED; LED_0603_1608Metric
D3: LED; LED_0603_1608Metric_Castellated
D4: P6SMB6.8CA; D_SMB
D5, D6: ESD5302F; SOT-23
FB1, FB2, FB3: FERRET; R_0805
J1: UART; PinHeader_1x04_P2.00mm_Vertical_nosilk_center
J2: SD; microSD_HC_Hirose_DM3D-SF
J3: USB; USB-C 16Pin
J4: OTG; PinHeader_1x04_P2.00mm_Vertical_nosilk_center
J5, J6, J7: PJ-3270
J8: 49F-1201GYD2NL; 49F-1201GYDXNL
L1, L2, L3, L4: 2.2uH; L_Taiyo-Yuden_MD-3030
L5: 2.2nH; L_0402
MK1: Mic; B4013AM422-42
Q1: DTA114YKA; SOT-23
R1, R32, R33, R61, R62: 100; R_0402
R2, R15, R34, R54, R76, R77, R81: 22; R_0402
R3, R4, R14, R24, R25, R30, R35, R36, R39, R86: 5k1; R_0402
R6, R22, R23, R29, R47, R52, R66, R67, R68, R69: DNP; R_0402
R7, R8, R9, R10, R11, R12, R13, R18, R26, R42, R58, R59, R60, R63, R64, R65, R70, R71, R72, R73, R74, R75: 47k; R_0402
R16, R21, R40, R78: 200k; R_0402
R17, R28, R37, R41, R48, R49, R50, R51, R79, R80, R87, R88: 2k2; R_0402
R27: 0R; R_0805
R31: 3k3; R_0402
R38: 3k9; R_0402
R43: 680; R_0402
R44, R45, R46: 0; R_0402
R82, R83: 240; R_0402
R84: 10M; R_0402
R89: 6k04; R_0402
R90, R91, R92, R93: 51; R_0402
SW3: RST; SW_SPST_PTS810
U1: AllWinner-S3(FBGA-234); FBGA-234(Pitch-0.65mm_Pad-0.3mm_11x11x1.08mm)
U3: AXP209(QFN-48); QFN-48-1EP_6x6mm_P0.4mm_EP4.05x4.05mm
U4: SY8089AAAC; SOT-23-5
U5: SY6280AAC; SOT-23-5
U6: SSM2603; LFCSP-28-5x5mm-0.5mm-EP3.14x3.14mm
U7: AP6236; LGA_44_12x12mm_0.9mm
X1: 26Mhz TCXO; 2016_SMD_CRYSTAL
Y1: 12.288Mhz; Oscillator_3225
Y2: 32.768kHz; Crystal_SMD_3215-2Pin_3.2x1.5mm
Y3: 24MHz; Oscillator_3225

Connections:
+1V1: C18.1, C22.1, C33.1, C35.1, C36.1, C39.1, C92.1, L2.2, U1.G12, U1.H12, U1.J11, U1.J12, U1.K8, U1.K9, U1.K11, U1.L8, U1.M8, U1.N5, U3.10
+1V2: C27.1, U3.41
+2V5: C7.1, U3.19
+2V8: C29.1, U3.11
+3.0VA: C26.1, C60.1, C65.1, C89.1, FB2.2, FB3.2, R40.1, U1.L6, U1.M7, U3.12, U4.1, U6.5
+3.3V_RTC: C25.1, C98.1, R18.2, R26.1, R86.2, U1.N6, U3.28, U3.29
+3V3: C1.1, C21.1, C23.1, C38.1, C62.1, C66.1, C72.1, C73.1, C74.1, C76.1, C95.1, FB1.1, J1.4, J8.9, J8.11, L1.2, R7.2, R8.2, R9.2, R10.2, R11.2, R12.2, R13.2, R48.2, R49.2, R50.2, R51.2, R64.1, R65.1, R70.1, R71.1, R72.1, R73.1, R74.1, R75.1, U1.H11, U1.L11, U1.L12, U1.M4, U1.M5, U1.M11, U1.M12, U1.N7, U1.P5, U1.P12, U3.17, U6.3, U7.9, U7.22, X1.4
+5V: C11.1, C14.1, C42.1, D4.1, J3.A4, J3.A9, J3.B4, J3.B9, R14.2, U3.32, U3.33, U5.5
+5V_USBOTG: C6.1, C43.1, C45.1, J4.4, R37.1, U3.31, U5.1
/Power/NMI: R18.1, U3.48
AP_CK32KO: R76.1, R86.1, U1.P3
AP_WAKE_BT: U1.F12, U7.6
BT_DIS_N: R2.2, U7.34
BT_PCM_CLK: R67.1, U1.P14, U6.7
BT_PCM_DIN: R68.1, U1.M13, U6.10
BT_PCM_DOUT: R69.1, U1.T15, U6.8
BT_PCM_SYNC: R54.2, R66.1, U1.T14, U6.9
BT_UART_CTS: U1.B8, U7.44
BT_UART_RTS: U1.C4, U7.41
BT_UART_RX: R74.2, U1.B3, U7.43
BT_UART_TX: U1.B4, U7.42
BT_WAKE_AP: R75.2, U1.N14, U7.7
EPHY_LINK_LED: R87.1, U1.K5
EPHY_RX_N: J8.2, R90.1, U1.F1
EPHY_RX_P: J8.1, R91.1, U1.F2
EPHY_SPD_LED: R88.1, U1.L5
EPHY_TX_N: J8.8, R92.1, U1.E2
EPHY_TX_P: J8.7, R93.1, U1.E3
GND: AE1.2, C1.2, C2.2, C3.2, C4.2, C5.2, C6.2, C7.2, C8.2, C9.1, C10.2, C11.2, C12.2, C13.2, C14.2, C15.2, C16.2, C17.2, C18.2, C19.2, C20.2, C21.2, C22.2, C23.2, C24.2, C25.2, C26.2, C27.2, C28.2, C29.2, C30.2, C31.2, C32.2, C33.2, C34.2, C35.2, C36.2, C37.2, C38.2, C39.2, C41.2, C42.2, C43.2, C44.2, C45.2, C48.2, C49.2, C51.2, C52.2, C60.2, C61.2, C62.2, C65.2, C66.2, C69.2, C72.2, C73.2, C74.2, C75.1, C76.2, C77.1, C83.2, C85.2, C88.2, C89.2, C90.2, C92.2, C93.2, C94.2, C95.2, C96.2, C97.2, C98.2, C100.1, C101.1, C102.1, C103.1, C104.2, D1.1, D2.1, D3.1, D4.2, D5.3, D6.3, J1.1, J2.6, J2.9, J2.11, J3.A1, J3.A12, J3.B1, J3.B12, J4.1, R15.2, R16.2, R17.2, R21.2, R24.2, R25.2, R27.1, R29.1, R32.2, R34.2, R35.2, R36.2, R38.2, R39.1, R78.2, R80.2, R81.2, R82.2, R83.2, R89.1, SW3.1, U1.A1, U1.A16, U1.C9, U1.D4, U1.D5, U1.D6, U1.D7, U1.D8, U1.D9, U1.D10, U1.D11, U1.D12, U1.E4, U1.E5, U1.E6, U1.E7, U1.E8, U1.E9, U1.E10, U1.E11, U1.E14, U1.F9, U1.F10, U1.F11, U1.G4, U1.G5, U1.G6, U1.G7, U1.G9, U1.G10, U1.G11, U1.H3, U1.H4, U1.H5, U1.H7, U1.H9, U1.H10, U1.J3, U1.J4, U1.J6, U1.J7, U1.J9, U1.J10, U1.K3, U1.K4, U1.K6, U1.K7, U1.K10, U1.K12, U1.L4, U1.L7, U1.L9, U1.L10, U1.M10, U1.N4, U1.N8, U1.P8, U1.R5, U1.T1, U1.T16, U3.9, U3.16, U3.22, U3.46, U3.49, U4.2, U5.2, U6.4, U6.EP, U7.1, U7.20, U7.31, U7.33, U7.36, X1.2, Y1.2, Y1.4, Y3.2, Y3.4
GNDA: C46.2, C50.2, C53.2, C54.2, C55.2, C58.2, C59.2, C70.2, C71.2, J5.4, J6.4, J7.4, MK1.1, R27.2, R42.2, R47.2, R52.2, R58.1, R59.2, R60.1, R63.2, U6.15, U6.19
GPIO_LED1: R3.1, U1.C7
GPIO_LED2: R4.1, U1.C8
GPIO_RST: R6.2, SW3.2, U1.A2
IPS: C5.1, C8.1, C10.1, C16.1, C17.1, C19.1, C20.1, C24.1, C28.1, C30.1, Q1.2, U3.7, U3.13, U3.14, U3.21, U3.34, U3.35, U3.40, U3.44, U4.4
MIC_DET: R40.2, R41.1, U1.B5
MIPI_SCK: R51.1, U1.G16, U3.2, U6.28
MIPI_SDA: R50.1, U1.J16, U3.1, U6.27
unnamed: AE1.1, C75.2, L5.1
unnamed: C3.1, R78.1, U1.N10
unnamed: C4.1, FB1.2, J2.4
unnamed: C9.2, U3.24
unnamed: C12.1, U3.47
unnamed: C13.1, J3.S1, R21.1
unnamed: C15.1, U3.38, U3.39, U3.42
unnamed: C46.1, C47.2, MK1.2, R42.1, R43.1
unnamed: C47.1, R46.1
unnamed: C48.1, C49.1, L4.1, U7.23
unnamed: C50.1, C57.2, R45.2, R47.1
unnamed: C51.1, U6.1, Y1.3
unnamed: C52.1, U6.2, Y1.1
unnamed: C53.1, C56.2, R44.2, R52.1
unnamed: C54.1, C58.1, FB3.1, U6.18
unnamed: C55.1, C59.1, FB2.1, U6.12
unnamed: C56.1, U6.24
unnamed: C57.1, U6.23
unnamed: C61.1, C69.1, U6.20
unnamed: C63.1, U6.17
unnamed: C63.2, R58.2, R61.2
unnamed: C64.1, U6.16
unnamed: C64.2, R60.2, R62.2
unnamed: C67.1, U6.14
unnamed: C67.2, C71.1, J6.5, R63.1
unnamed: C68.1, U6.13
unnamed: C68.2, C70.1, J6.2, R59.1
unnamed: C77.2, C78.1, L5.2
unnamed: C78.2, U7.2
unnamed: C82.1, C83.1, C88.1, R79.1, R80.1, U1.H6
unnamed: C85.1, U1.M9
unnamed: C90.1, U1.T5
unnamed: C93.1, U1.R4, Y3.1
unnamed: C94.1, U1.P4, Y3.3
unnamed: C96.1, R84.2, U1.T3, Y2.1
unnamed: C97.1, R84.1, U1.R3, Y2.2
unnamed: C100.2, R90.2, R91.2
unnamed: C101.2, R92.2, R93.2
unnamed: C102.2, J8.3
unnamed: C103.2, J8.6
unnamed: C104.1, J8.SH
unnamed: D1.2, R3.2
unnamed: D2.2, R4.2
unnamed: D3.2, R14.1
unnamed: D5.1, J1.3, R33.1
unnamed: D5.2, J1.2, R1.1
unnamed: J3.A5, R24.1
unnamed: J3.A6, J3.B6, R23.1
unnamed: J3.A7, J3.B7, R22.1
unnamed: J3.B5, R25.1
unnamed: J5.2, R44.1
unnamed: J5.3, R41.2
unnamed: J5.5, R45.1
unnamed: J7.2, R62.1
unnamed: J7.5, R61.1
unnamed: J8.10, R88.2
unnamed: J8.12, R87.2
unnamed: L1.1, U3.15
unnamed: L2.1, U3.8
unnamed: L3.1, U4.3
unnamed: L4.2, U7.21
unnamed: Q1.1, R6.1
unnamed: Q1.3, R17.1, U3.4
unnamed: R2.1, U1.C13
unnamed: R15.1, U3.37
unnamed: R16.1, U3.23
unnamed: R28.2, R29.2, U3.27
unnamed: R30.2, R31.1, U4.5
unnamed: R31.2, R32.1
unnamed: R34.1, U1.M6
unnamed: R36.1, U5.3
unnamed: R43.2, U6.21
unnamed: R46.2, U6.22
unnamed: R48.1, U6.25
unnamed: R49.1, U6.26
unnamed: R54.1, U6.11
unnamed: R66.2, U7.28
unnamed: R67.2, U7.26
unnamed: R68.2, U7.27
unnamed: R69.2, U7.25
unnamed: R76.2, U7.24
unnamed: R77.2, U7.17
unnamed: R81.1, U1.R13
unnamed: R82.1, U1.J5
unnamed: R83.1, U1.F5
unnamed: R89.2, U1.P6
unnamed: U7.10, X1.3
RESETn: C2.1, R26.2, U1.P7, U3.25
SDC0_CLK: J2.5, R10.1, U1.P2
SDC0_CMD: J2.3, R9.1, U1.N2
SDC0_D0: J2.7, R11.1, U1.P1
SDC0_D1: J2.8, R12.1, U1.R1
SDC0_D2: J2.1, R7.1, U1.M2
SDC0_D3: J2.2, R8.1, U1.N3
SDC0_DET#: J2.10, R13.1, U1.M1
UART1_RX: R1.2, U1.M14
UART1_TX: R33.2, U1.M15
USB_DRV: R35.1, U3.6, U5.4
USB_D_N: D6.2, J4.3, R22.2, U1.R2
USB_D_P: D6.1, J4.2, R23.2, U1.T2
USB_ID: R39.2, U1.R14
USB_VBUSDET: C44.1, R37.2, R38.1, U1.A5
VCC-DDR: C31.1, C32.1, C34.1, C37.1, C41.1, C82.2, L3.2, R30.1, R79.2, U1.F6, U1.F7, U1.F8, U1.G8, U1.H8, U1.J8
VINT: R28.1, U3.26
WL_PMU_EN: R73.2, U1.E16, U7.12
WL_SDIO_CLK: R77.1, U1.P16
WL_SDIO_CMD: R72.2, U1.N15, U7.16
WL_SDIO_D0: R71.2, U1.P15, U7.18
WL_SDIO_D1: R70.2, U1.N16, U7.19
WL_SDIO_D2: R65.2, U1.R15, U7.14
WL_SDIO_D3: R64.2, U1.R16, U7.15
WL_WAKE_AP: U1.C5, U7.13

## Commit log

2020-11-17 no drc error
    [Audio.sch, MIPI.sch, OtterCastAudioV2.kicad_pcb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]
2020-11-18 working on silkscreen
    [OtterCastAudioV2.kicad_pcb]
2020-11-19 regenerated gerber
    [OtterCastAudioV2-B_Cu.gbl, OtterCastAudioV2-B_Mask.gbs, OtterCastAudioV2-B_Paste.gbp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]
2020-11-19 added edgerails and production files
    [BOM.csv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]
2021-02-12 fixed axp bug, fixed schematics, fixed eeprom
    [MIPI.sch, OtterCastAudioV2.kicad_pcb, OtterCastAudioV2.sch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]
2021-02-14 fixed ETH, added AGND plane to prevent Line-In Noise, optimized power
    [MIPI.sch, OtterCastAudioV2.kicad_pcb]
2021-02-14 fixed ETH cur ref
    [MIPI.sch, OtterCastAudioV2.kicad_pcb]
2021-02-18 fixed axp rst, gpio rst, din, dout, eth
    [MIPI.sch, OtterCastAudioV2.kicad_pcb, OtterCastAudioV2.sch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]
2021-02-18 removed 3d files
    [OtterCastAudioV2_3D.FCStd]
2021-02-18 added gitignore, finished v2.1, exported gerber, moved 2.0 data
    [BOM.csv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]
2021-02-19 added i2c to axp209, fixed tvs diodes
    [BOM_v2.1.csv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]
2021-02-19 changed RST to cfg
    [OtterCastAudioV2.kicad_pcb]
2021-02-19 finalized v2.1, ordered boards
    [Audio.sch, BOM_v2.1.csv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]
2021-02-27 broken links
    [Audio.sch, MIPI.sch, OtterCastAudioV2.sch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]
2021-03-01 beautify kicad project
    [Audio.sch, MIPI.sch, OtterCastAudioV2.kicad_pcb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]
2021-03-01 exported pdf
    [MIPI.sch, OtterCastAudioV2.sch, Power.sch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]
2021-03-09 added cad
    [OtterCastLogo.dxf, case_bot.ipt, case_top.ipt]
2021-03-09 removed ibom
    [OtterCastAudioV2.kicad_pcb]
2021-03-09 removed scad file
    [RJ45.scad]
2021-03-23 added readme, removed old files
    [BOM.csv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]
2021-03-24 renamed folder
    [BOM_v2.1.csv, POS_v2.1.csv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]
2022-04-01 updated to kicad 6
    [Audio.kicad_sch, MIPI.kicad_sch, OtterCastAudioV2.kicad_pcb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]
2022-04-01 deleted old files
    [Audio.sch, MIPI.sch, OtterCastAudioV2.sch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]
2022-04-01 updated files to kicad 6
2024-01-16 updated bom and pos
    [BOM_v2.1.csv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]
2024-01-16 updated kicad files
    [Audio.kicad_sch, MIPI.kicad_sch, OtterCastAudioV2.kicad_pcb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]
2024-01-16 added bottom pos
    [OtterCastAudioV2-bottom-pos.csv]
